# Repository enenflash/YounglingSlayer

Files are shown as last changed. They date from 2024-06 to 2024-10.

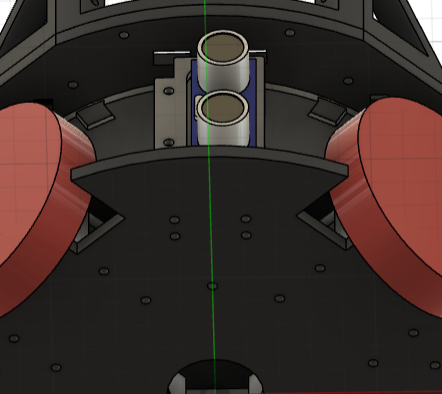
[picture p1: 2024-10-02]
mechanical design/metro/L1.png

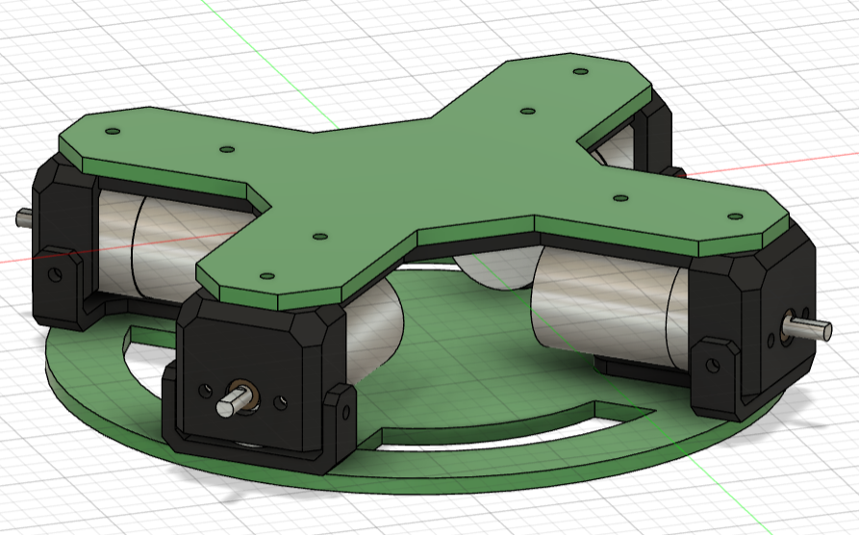
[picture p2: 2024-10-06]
mechanical design/nationals/L2-motors-LS.png

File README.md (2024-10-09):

# YounglingSlayer
Team repository for Robocup Junior Lightweight Australia 2024

## Team Info
- Members: Isabelle Tang (Captain), Ryan Beikrasouli (Programmer), Cruz Barry-Hardy (3D Designer), Albie Gardiner (3D Designer)
- State: Western Australia
- School: Rossmoyne Senior High School

## Programming
We use C++ in [ArduinoIDE](https://www.arduino.cc/en/software/) to program our microcontroller (Teensy 4.1). (See code-explanations)
We also use Raspberry Pi Pico as part of our line sensor.

## 3D Printing
We design our parts in [Fusion360](https://www.autodesk.com/au/products/fusion-360/education). (See mechanical design/)
All parts are printed in PLA.

## PCB Design
We design our PCBs in [KiCAD 7.0](https://www.kicad.org/) and order from [JLCPCB](https://jlcpcb.com/). (See pcbs/).
The schematics are based on circuits we tested using breadboards.

All designs are original other than the [BBR IR Seeker](https://irseeker.buildingblockrobotics.com/)

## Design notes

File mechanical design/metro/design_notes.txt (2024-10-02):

Total weight: 1.372kg

General design notes:
> The motors are not in a perfect 'x' shape but are still at 45 degrees (layout.png).
  - The motors are pushed to the side to give more space for the ball catcher at the front
> We are using breadboards to test out the circuitry and plan to use PCBs later on.
> The wheel size of 7cm was chosen - majority of the design is based on the wheel size (planning.png)
- Last year in standard, our lego wheel size was also ~7cm.

Wheel (wheel/fusion.png):
> The wheel is split into 2 layers of rollers each containing 10 rollers.
> Each roller is wrapped with heatshrink tubing and has a hole for an axle.
(See wheel/assembly.mp4 for assembly)
> A coupling piece is used to attach the wheel to the motor.
- Contains 3mm holes for grub screws to apply pressure on the shaft to prevent the wheel from slipping out.
- The wheel encases the coupling so the layers do not fall off the motor shaft.

Design is split into 3 sections:
> Layer 1 (Bottom layer)
  - holds ultrasonics
  - connects motor mounts from the bottom
> Layer 2 (Middle layer)
  - connects motor mounts from the top
  - goes under IR and has pillars connecting to L3
> Layer 3 (Top layer)
  - goes on top of IR
  - holds components that go on top such as breadboard, battery, switches
  - ball catcher hangs down from L3
  - goal stopper/handle at the back (stops the robot from going into its own goal)

Layer 1 (L1.png):
> Mounts ultrasonics and motor mounts
> Has indents on diagonals for motors

Layer 2 and motor mounts (L2_motor_mounts):
> Motor mounts encase the motor (the motors are attached via 2 screws at the front)
> Pillars on top of L2 go through holes in the IR to connect to L3.

Layer 3 (L3_holes.png):
> Wires (motor wires, ultrasonic wires) come from holes under the breadboard
> Battery is zip-tied using the holes to the left and right of its
> Breadboard is mounted to L3

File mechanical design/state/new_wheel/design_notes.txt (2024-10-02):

> Reduced wheel size from ~7cm to 6.2cm (including rollers)
  - Increase space for ball catcher and ultrasonics
  - Gain more torque from reduced speed
  - Less rollers to deal with when assembling (14 instead of 20 total)
> 2 screw holes and 2 middle plate 'sticks' instead of 4 each
> Coupling is thicker to prevent it from breaking/cracking
> Tighter hole for motor shaft to prevent wobble

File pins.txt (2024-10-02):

// Motor Pins
#define TL_PWM 5
#define TL_DIR 4
#define TR_PWM 6
#define TR_DIR 7
#define BL_PWM 3
#define BL_DIR 2
#define BR_PWM 9
#define BR_DIR 8

// Ultrasonic Pins
#define USR_TRIG 34
#define USR_ECHO 33
#define USL_TRIG 22
#define USL_ECHO 23
#define USB_TRIG 28
#define USB_ECHO 27

// IDLE SWITCH
#define IDLE_PIN 40

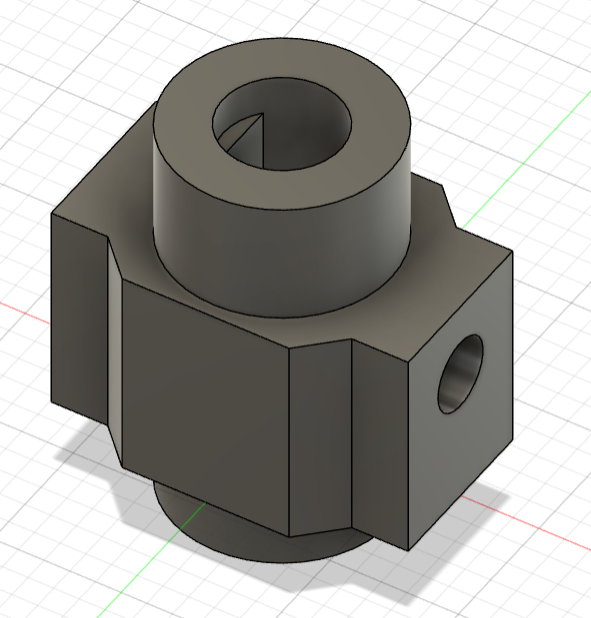
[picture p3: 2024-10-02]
mechanical design/state/new_wheel/coupling.png

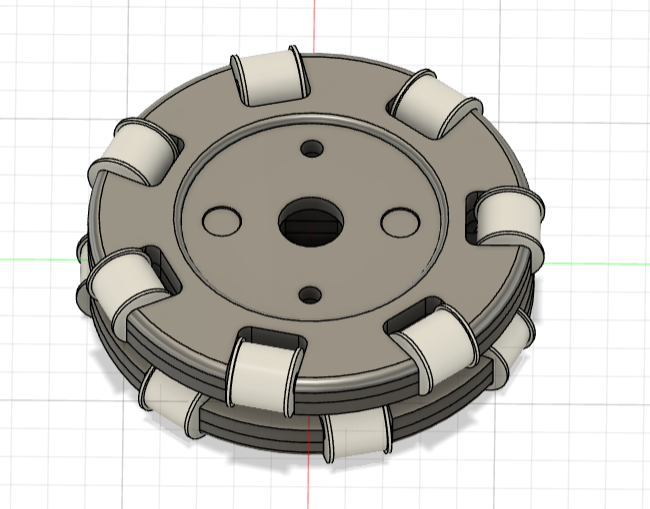
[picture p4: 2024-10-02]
mechanical design/state/new_wheel/6cm_wheel.png

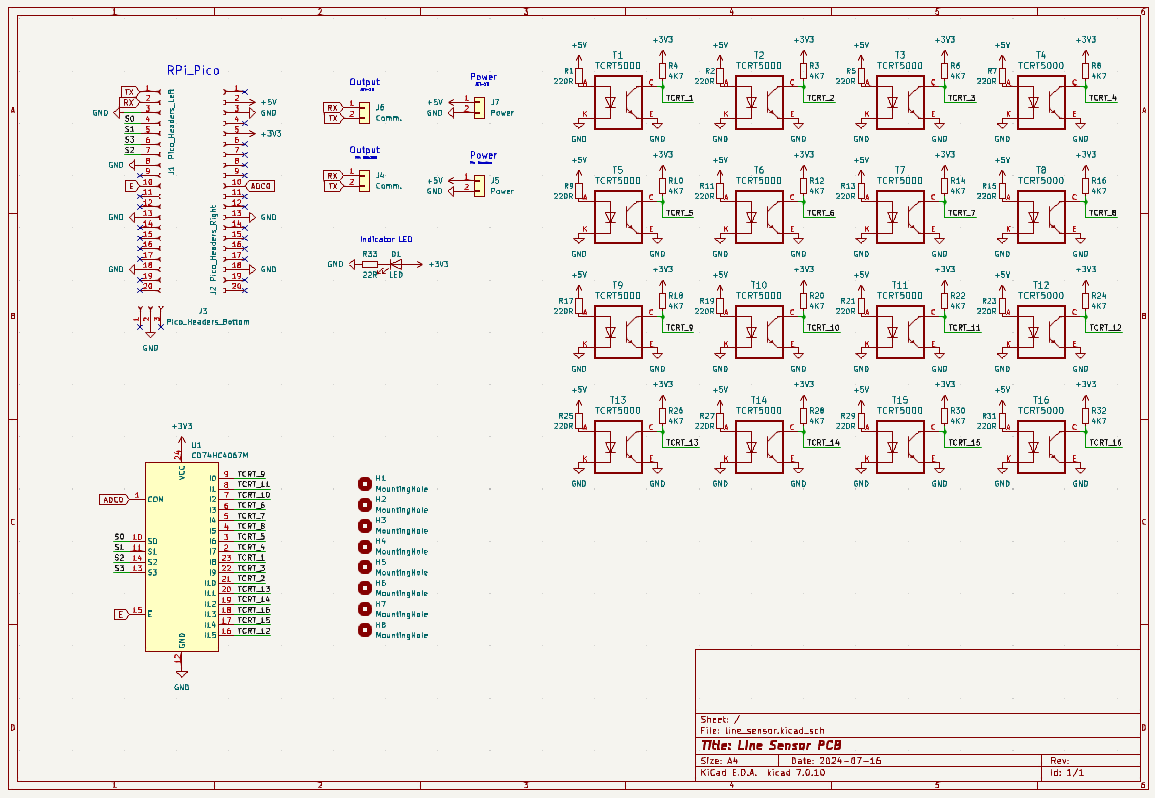
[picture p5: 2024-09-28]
pcbs/line_sensor-26-08/schematic.png

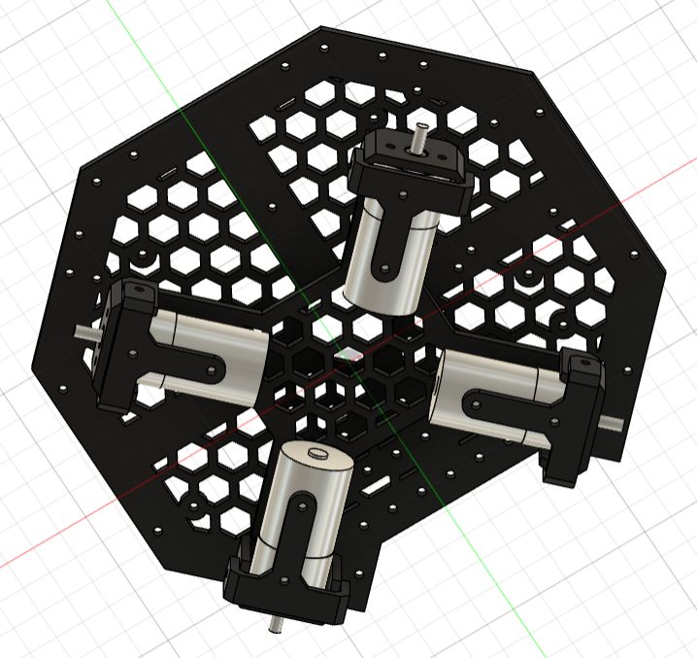
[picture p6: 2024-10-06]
mechanical design/nationals/hexagons.png

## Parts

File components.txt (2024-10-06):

Microcontroller: Teensy 4.1
- Website: https://www.pjrc.com/store/teensy41.html

Battery: 12V Lithium Ion DC
- Website: https://au.lightmalls.com/12v-4000mah-18650-lithium-ion-dc-12-6v-super-rechargeable-battery-pack

IR Sensor: BBR IR Sensor V2 (I2C):
- Website: https://buildingblockrobotics.com/products/ir-seeker (note this is v3)
- Tutorial: https://irseeker.buildingblockrobotics.com/ 

IMU: Adafruit BNO055 9-DOF IMU (I2C)
- Website: https://www.adafruit.com/product/2472
- Tutorial: https://learn.adafruit.com/adafruit-bno055-absolute-orientation-sensor/arduino-code

Adjustable Voltage Step-down: 
- https://www.altronics.com.au/p/z6334-dc-dc-buck-module-3-40v-input/

Ultrasonics: HC-SR04
- https://core-electronics.com.au/hc-sr04-ultrasonic-module-distance-measuring-sensor.html

Bluetooth Module: HC-05
- https://core-electronics.com.au/bluetooth-module-hc-05.html

Line Sensor PCB: Custom made (UART)
- Sub-mcu: Raspberry Pi Pico
- Multiplexer: CD74HC4067M
- Reflective light sensors: TCRT-5000

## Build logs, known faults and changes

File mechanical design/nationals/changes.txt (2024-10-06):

There are 3 new PCBs: (pcbs/)
> Top Board
  - Contains IMU, bluetooth module, switches and battery connector
> Bottom Board
  - Contains Teensy 4.1 and main circuits: motor, ultrasonic and line sensor wires
> Line sensor

Reused parts:
> Ultrasonic mounts and cage pieces
> Goal stopper
> Wheels

L2 and Motors (L2-motors-LS.png)
> The same concept is used where the motors directly attach to L2
> The Line sensor is mounted below the motors and connects to L2

Support pillars
> Metal M3 standoffs are used to connect L2 to the IR mount
  - The metal standoffs are stronger and thinner
  - The bottom board is held between L2 and the metal standoffs
> There are 2 supports above each motor instead of 1

IR mount
> The IR mount is similar to the old one but the ring connecting the dividers is further out

Wheel guards (wheel_guard.png)
> Wheel guards are used to hold the wheels in place
  - Reduces the occurence of wheels falling out
  - Protects wheels from other robots

Wiring (core.png)
> JST-XH headers and housings are used to securely attach component wiring
> Wires are crimped by hand to the exact length needed

Hexagons (hexagons.png)
> Hexagon patterns were added throughout the robot to reduce the weight of printed parts

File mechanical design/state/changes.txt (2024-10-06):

Total Weight: 1.1kg

Structural changes:

> Change in shape
  - Removed the circular shape of the layers to become an octogon
  - Makes positioning of pieces easier

> Removing Layer 1 (bottom_view.png)
  - L1 was removed to lose weight as ultrasonics can be attached from L3

> Combining L2 with motor mounts (L2-motors.png)
  - Motor mounts were removed to lose weight
  - L2 connects to motors directly
  - Support pillars connecting L2 to L3 are printed separately so that a change in height does not requite redesigns of L2

> IR Mount (IR_mount.png, structure.png)
  - L2 connects to the IR mount using support pillars
  - The IR Mount supports the IR from the bottom (not screwed in)
  - It also separates the individual sensors to reduce interference and incorrect readings
  - The IR Mount connects to L3 through the horizontal and vertical square holes

> Goal stopper used as a handle
  - The goal stopper was redesigned to be easily printable and able to be used as a handle

> Double decker breadboard
  - We intended to use PCBs during states but due to delays we had to use breadboards again
  - Half breadboards are stacked over each other to reduce space

> Cage and ultrasonics
  - Instead of mounting ultrasonics from L1 they are mounted directly to the cage
  - The cage hangs from L3 via a single screw
  - Ultrasonics are horizontal to allow them to be lower and make connecting pins easier

> Battery mount
  - Battery is mounted by encasing it instead of zip ties

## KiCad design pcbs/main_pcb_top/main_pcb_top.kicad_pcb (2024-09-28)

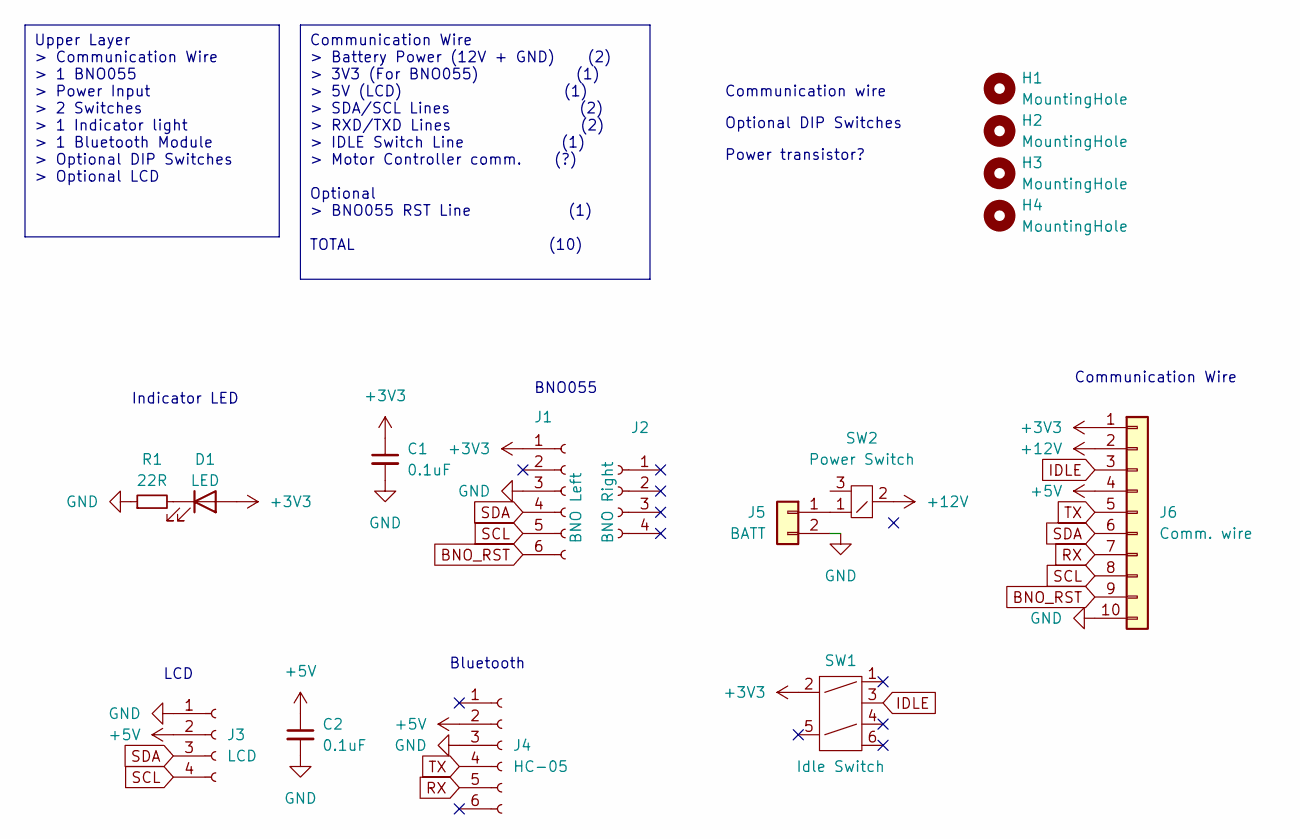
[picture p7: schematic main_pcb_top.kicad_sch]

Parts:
C1, C2: 0.1uF; C_0402_1005Metric
D1: LED; LED_0805_2012Metric
H1, H2, H3, H4: MountingHole; MountingHole_3.2mm_M3_Pad
J1: BNO Left; PinSocket_1x06_P2.54mm_Vertical
J2: BNO Right; PinSocket_1x04_P2.54mm_Vertical
J3: LCD; PinSocket_1x04_P2.54mm_Vertical
J4: HC-05; PinSocket_1x06_P2.54mm_Vertical
J5: BATT; JST_XH_B2B-XH-A_1x02_P2.50mm_Vertical
J6: Comm. wire; IDC-Header_2x05_P2.54mm_Vertical
R1: 22R; R_0805_2012Metric
SW1: Idle Switch; Switch_DPDT_S2060
SW2: Power Switch; Switch_SPDT_S2070

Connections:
+3V3: C1.1, D1.2 (A), J1.1, J6.1, SW1.2
+5V: C2.1, J3.2, J4.2, J6.4
+12V: J6.2, SW2.2
BNO_RST: J1.6, J6.9
GND: C1.2, C2.2, J1.3, J3.1, J4.3, J5.2, J6.10, R1.1
IDLE: J6.3, SW1.3
unnamed: D1.1 (K), R1.2
unnamed: J5.1, SW2.1
RX: J4.5, J6.7
SCL: J1.5, J3.4, J6.8
SDA: J1.4, J3.3, J6.6
TX: J4.4, J6.5

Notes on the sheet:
Upper Layer > Communication Wire > 1 BNO055 > Power Input > 2 Switches > 1 Indicator light > 1 Bluetooth Module > Optional DIP Switches > Optional LCD
Communication Wire > Battery Power (12V + GND) (2) > 3V3 (For BNO055) (1) > 5V (LCD) (1) > SDA/SCL Lines (2) > RXD/TXD Lines (2) > IDLE Switch Line (1) > Motor Controller comm. (?) Optional > BNO055 RST Line (1) TOTAL (10)
Power transistor?
Bluetooth
Communication wire
Optional DIP Switches
BNO055
LCD
Indicator LED
Communication Wire

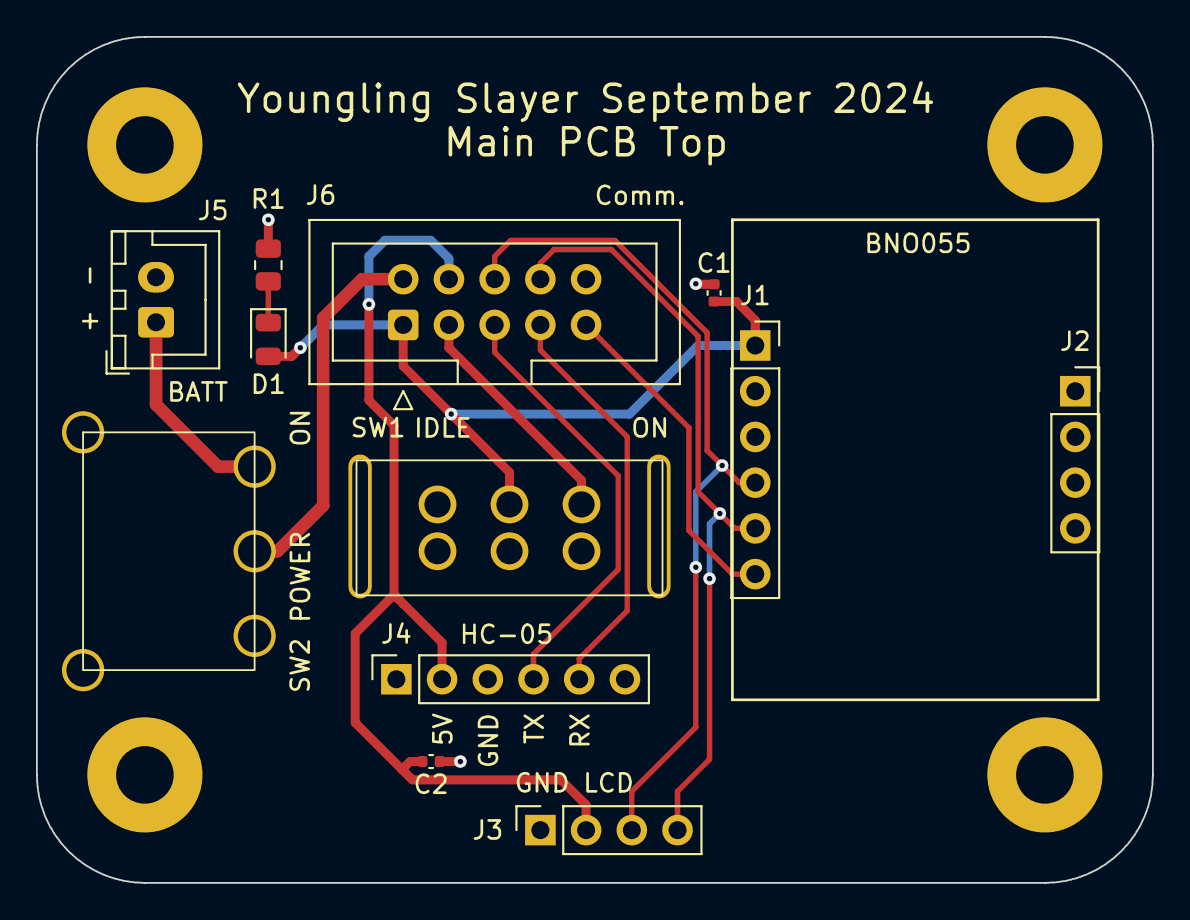
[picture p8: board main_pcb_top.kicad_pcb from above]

Board: 2 copper layers, 62.0 x 47.0 mm, 16 parts (0 on the bottom side), 12 nets.

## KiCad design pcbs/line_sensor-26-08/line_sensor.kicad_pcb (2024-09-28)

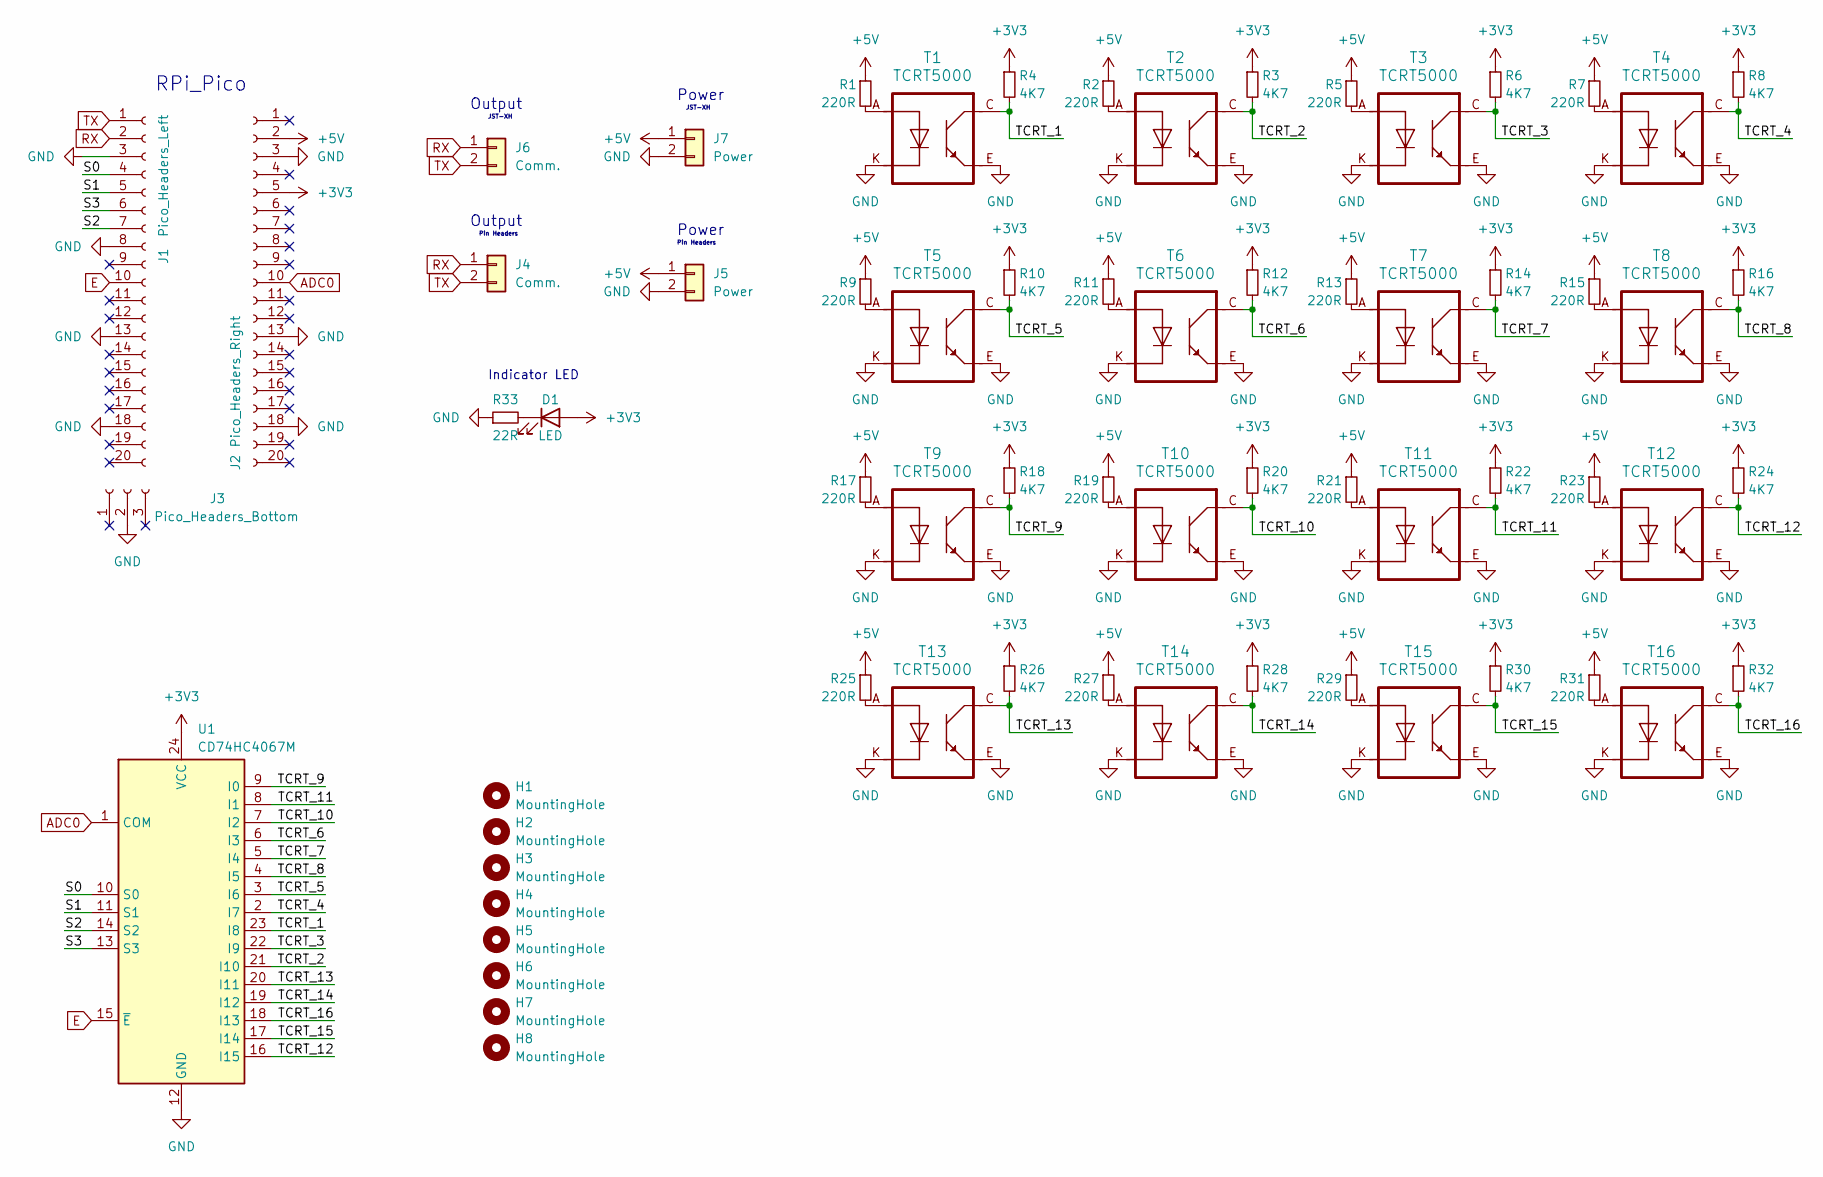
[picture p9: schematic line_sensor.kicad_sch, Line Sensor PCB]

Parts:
D1: LED; LED_0805_2012Metric
H1, H2, H3, H4, H5, H6, H7, H8: MountingHole; MountingHole_3.2mm_M3_Pad
J1: Pico_Headers_Left; PinSocket_1x20_P2.54mm_Vertical
J2: Pico_Headers_Right; PinSocket_1x20_P2.54mm_Vertical
J3: Pico_Headers_Bottom; PinSocket_1x03_P2.54mm_Vertical
J4: Comm.; PinSocket_1x02_P2.54mm_Vertical
J5: Power; PinSocket_1x02_P2.54mm_Vertical
J6: Comm.; JST_XH_B2B-XH-AM_1x02_P2.50mm_Vertical
J7: Power; JST_XH_B2B-XH-AM_1x02_P2.50mm_Vertical
R1, R2, R5, R7, R9, R11, R13, R15, R17, R19, R21, R23, R25, R27, R29, R31: 220R; R_0805_2012Metric
R3, R4, R6, R8, R10, R12, R14, R16, R18, R20, R22, R24, R26, R28, R30, R32: 4K7; R_0805_2012Metric
R33: 22R; R_0805_2012Metric
T1, T2, T3, T4, T5, T6, T7, T8, T9, T10, T11, T12, T13, T14, T15, T16: TCRT5000
U1: CD74HC4067M; SOIC-24W_7.5x15.4mm_P1.27mm

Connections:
+3V3: D1.2 (A), J2.5, R3.1, R4.1, R6.1, R8.1, R10.1, R12.1, R14.1, R16.1, R18.1, R20.1, R22.1, R24.1, R26.1, R28.1, R30.1, R32.1, U1.24 (VCC)
+5V: J2.2, J5.1, J7.1, R1.1, R2.1, R5.1, R7.1, R9.1, R11.1, R13.1, R15.1, R17.1, R19.1, R21.1, R23.1, R25.1, R27.1, R29.1, R31.1
/S0: J1.4, U1.10 (S0)
/S1: J1.5, U1.11 (S1)
/S2: J1.7, U1.14 (S2)
/S3: J1.6, U1.13 (S3)
/TCRT_1: R4.2, T1.C (Collector), U1.23 (I8)
/TCRT_2: R3.2, T2.C (Collector), U1.21 (I10)
/TCRT_3: R6.2, T3.C (Collector), U1.22 (I9)
/TCRT_4: R8.2, T4.C (Collector), U1.2 (I7)
/TCRT_5: R10.2, T5.C (Collector), U1.3 (I6)
/TCRT_6: R12.2, T6.C (Collector), U1.6 (I3)
/TCRT_7: R14.2, T7.C (Collector), U1.5 (I4)
/TCRT_8: R16.2, T8.C (Collector), U1.4 (I5)
/TCRT_9: R18.2, T9.C (Collector), U1.9 (I0)
/TCRT_10: R20.2, T10.C (Collector), U1.7 (I2)
/TCRT_11: R22.2, T11.C (Collector), U1.8 (I1)
/TCRT_12: R24.2, T12.C (Collector), U1.16 (I15)
/TCRT_13: R26.2, T13.C (Collector), U1.20 (I11)
/TCRT_14: R28.2, T14.C (Collector), U1.19 (I12)
/TCRT_15: R30.2, T15.C (Collector), U1.17 (I14)
/TCRT_16: R32.2, T16.C (Collector), U1.18 (I13)
ADC0: J2.10, U1.1 (COM)
E: J1.10, U1.15 (~E)
GND: J1.3, J1.8, J1.13, J1.18, J2.3, J2.13, J2.18, J3.2, J5.2, J7.2, R33.1, T1.E (Emitter), T1.K (Cathode), T2.E (Emitter), T2.K (Cathode), T3.E (Emitter), T3.K (Cathode), T4.E (Emitter), T4.K (Cathode), T5.E (Emitter), T5.K (Cathode), T6.E (Emitter), T6.K (Cathode), T7.E (Emitter), T7.K (Cathode), T8.E (Emitter), T8.K (Cathode), T9.E (Emitter), T9.K (Cathode), T10.E (Emitter), T10.K (Cathode), T11.E (Emitter), T11.K (Cathode), T12.E (Emitter), T12.K (Cathode), T13.E (Emitter), T13.K (Cathode), T14.E (Emitter), T14.K (Cathode), T15.E (Emitter), T15.K (Cathode), T16.E (Emitter), T16.K (Cathode), U1.12 (GND)
unnamed: D1.1 (K), R33.2
unnamed: R1.2, T1.A (Anode)
unnamed: R2.2, T2.A (Anode)
unnamed: R5.2, T3.A (Anode)
unnamed: R7.2, T4.A (Anode)
unnamed: R9.2, T5.A (Anode)
unnamed: R11.2, T6.A (Anode)
unnamed: R13.2, T7.A (Anode)
unnamed: R15.2, T8.A (Anode)
unnamed: R17.2, T9.A (Anode)
unnamed: R19.2, T10.A (Anode)
unnamed: R21.2, T11.A (Anode)
unnamed: R23.2, T12.A (Anode)
unnamed: R25.2, T13.A (Anode)
unnamed: R27.2, T14.A (Anode)
unnamed: R29.2, T15.A (Anode)
unnamed: R31.2, T16.A (Anode)
RX: J1.2, J4.1, J6.1
TX: J1.1, J4.2, J6.2

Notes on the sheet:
Output
Power
RPi_Pico
JST-XH
Pin Headers
Indicator LED

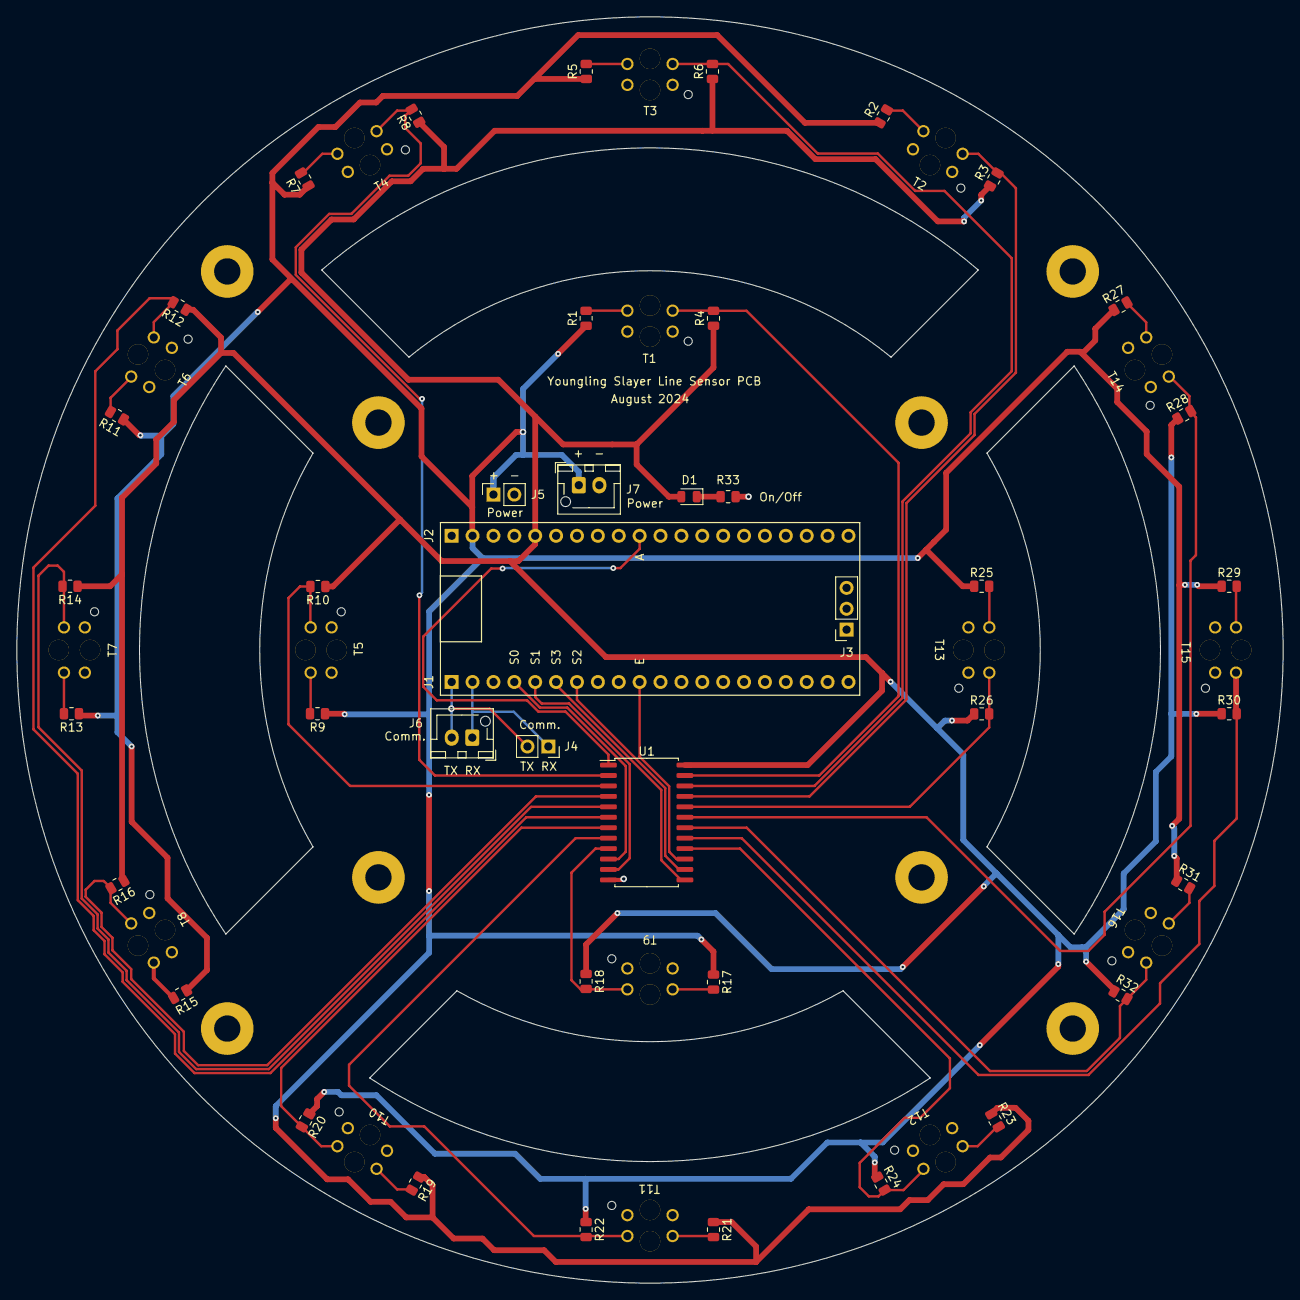
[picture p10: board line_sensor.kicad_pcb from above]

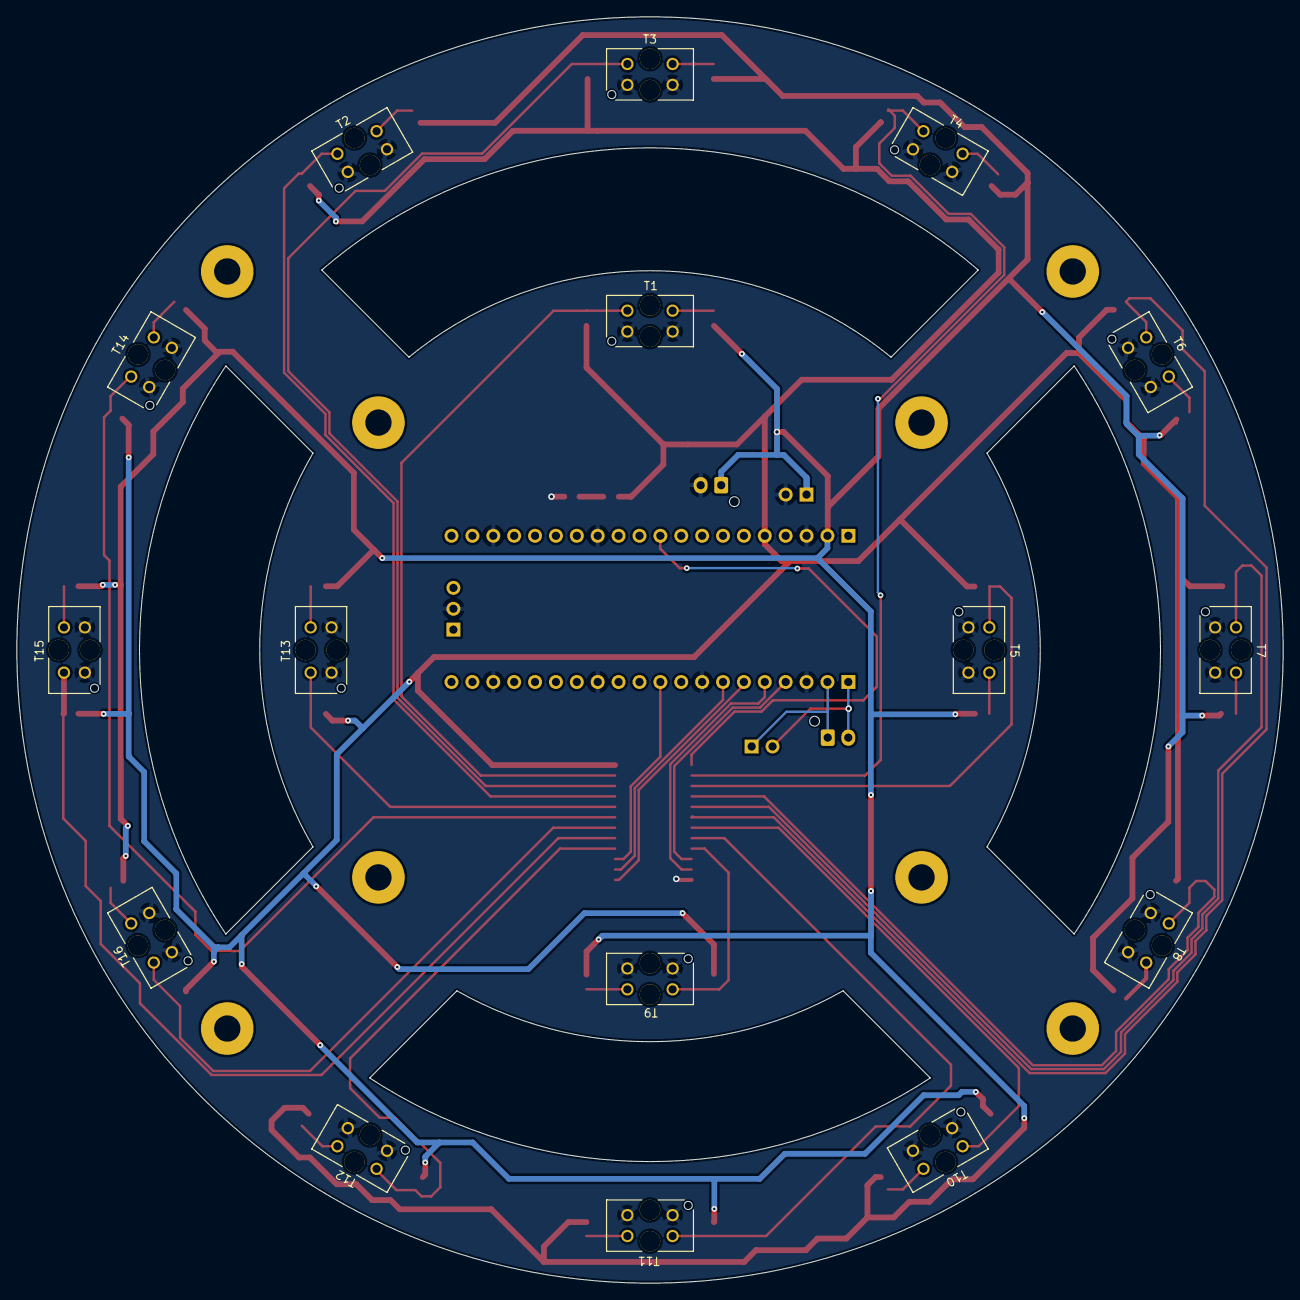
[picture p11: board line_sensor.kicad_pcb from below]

Board: 2 copper layers, 154.0 x 154.0 mm, 66 parts (16 on the bottom side), 44 nets.

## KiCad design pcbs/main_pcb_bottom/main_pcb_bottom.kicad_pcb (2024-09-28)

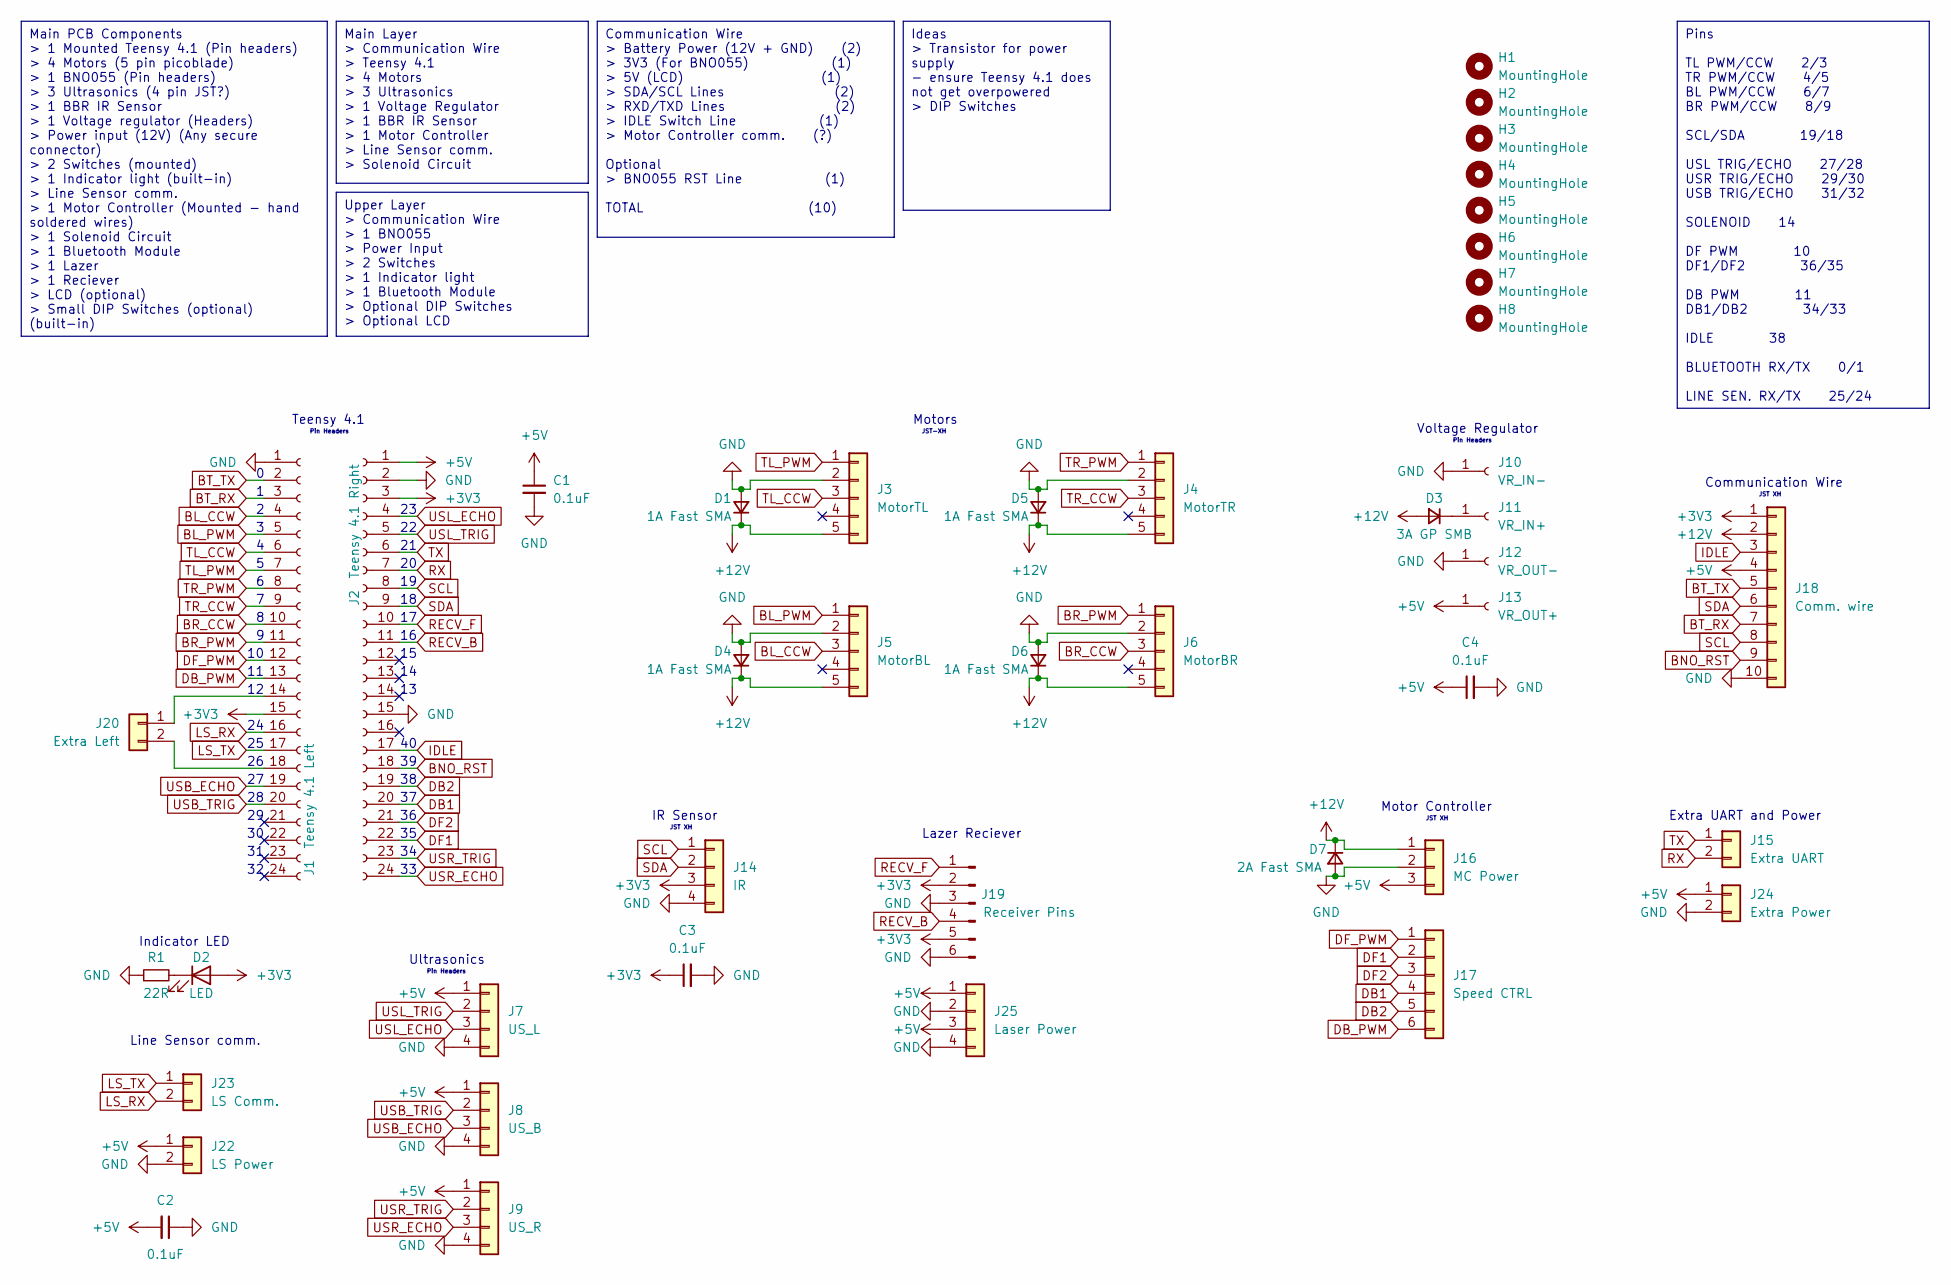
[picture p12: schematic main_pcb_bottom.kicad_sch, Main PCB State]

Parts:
C1, C2, C3, C4: 0.1uF; C_0402_1005Metric
D1, D4, D5, D6: 1A Fast SMA; D_SMA
D2: LED; LED_0805_2012Metric_Pad1.15x1.40mm_HandSolder
D3: 3A GP SMB; D_SMB
D7: 2A Fast SMA; D_SMA
H1, H2, H3, H4, H5, H6, H7, H8: MountingHole; MountingHole_3.2mm_M3_Pad
J1: Teensy 4.1 Left; PinSocket_1x24_P2.54mm_Vertical
J2: Teensy 4.1 Right; PinSocket_1x24_P2.54mm_Vertical
J3: MotorTL; JST_XH_B5B-XH-AM_1x05_P2.50mm_Vertical
J4: MotorTR; JST_XH_B5B-XH-AM_1x05_P2.50mm_Vertical
J5: MotorBL; JST_XH_B5B-XH-AM_1x05_P2.50mm_Vertical
J6: MotorBR; JST_XH_B5B-XH-AM_1x05_P2.50mm_Vertical
J7: US_L; JST_XH_B4B-XH-AM_1x04_P2.50mm_Vertical
J8: US_B; JST_XH_B4B-XH-AM_1x04_P2.50mm_Vertical
J9: US_R; JST_XH_B4B-XH-AM_1x04_P2.50mm_Vertical
J10: VR_IN-; PinSocket_1x01_P2.54mm_Vertical
J11: VR_IN+; PinSocket_1x01_P2.54mm_Vertical
J12: VR_OUT-; PinSocket_1x01_P2.54mm_Vertical
J13: VR_OUT+; PinSocket_1x01_P2.54mm_Vertical
J14: IR; JST_XH_B4B-XH-AM_1x04_P2.50mm_Vertical
J15: Extra UART; JST_XH_B2B-XH-AM_1x02_P2.50mm_Vertical
J16: MC Power; JST_XH_B3B-XH-AM_1x03_P2.50mm_Vertical
J17: Speed CTRL; JST_XH_B6B-XH-AM_1x06_P2.50mm_Vertical
J18: Comm. wire; IDC-Header_2x05_P2.54mm_Vertical
J19: Receiver Pins; PinHeader_1x06_P2.54mm_Vertical
J20: Extra Left; PinSocket_1x02_P2.54mm_Vertical
J22: LS Power; JST_XH_B2B-XH-AM_1x02_P2.50mm_Vertical
J23: LS Comm.; JST_XH_B2B-XH-AM_1x02_P2.50mm_Vertical
J24: Extra Power; JST_XH_B2B-XH-AM_1x02_P2.50mm_Vertical
J25: Laser Power; PinHeader_1x04_P2.54mm_Vertical
R1: 22R; R_0805_2012Metric_Pad1.20x1.40mm_HandSolder

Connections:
+3V3: C3.1, D2.2 (A), J1.15, J2.3, J14.3, J18.1, J19.2, J19.5
+5V: C1.1, C2.2, C4.1, J2.1, J7.1, J8.1, J9.1, J13.1, J16.3, J18.4, J22.1, J24.1, J25.1, J25.3
+12V: D1.1 (K), D3.2 (A), D4.1 (K), D5.1 (K), D6.1 (K), D7.1 (K), J3.5, J4.5, J5.5, J6.5, J16.1, J18.2
BL_CCW: J1.4, J5.3
BL_PWM: J1.5, J5.1
BNO_RST: J2.18, J18.9
BR_CCW: J1.10, J6.3
BR_PWM: J1.11, J6.1
BT_RX: J1.3, J18.7
BT_TX: J1.2, J18.5
DB1: J2.20, J17.4
DB2: J2.19, J17.5
DB_PWM: J1.13, J17.6
DF1: J2.22, J17.2
DF2: J2.21, J17.3
DF_PWM: J1.12, J17.1
GND: C1.2, C2.1, C3.2, C4.2, D1.2 (A), D4.2 (A), D5.2 (A), D6.2 (A), D7.2 (A), J1.1, J2.2, J2.15, J3.2, J4.2, J5.2, J6.2, J7.4, J8.4, J9.4, J10.1, J12.1, J14.4, J16.2, J18.10, J19.3, J19.6, J22.2, J24.2, J25.2, J25.4, R1.1
IDLE: J2.17, J18.3
LS_RX: J1.16, J23.2
LS_TX: J1.17, J23.1
unnamed: D2.1 (K), R1.2
unnamed: D3.1 (K), J11.1
unnamed: J1.14, J20.1
unnamed: J1.18, J20.2
RECV_B: J2.11, J19.4
RECV_F: J2.10, J19.1
RX: J2.7, J15.2
SCL: J2.8, J14.1, J18.8
SDA: J2.9, J14.2, J18.6
TL_CCW: J1.6, J3.3
TL_PWM: J1.7, J3.1
TR_CCW: J1.9, J4.3
TR_PWM: J1.8, J4.1
TX: J2.6, J15.1
USB_ECHO: J1.19, J8.3
USB_TRIG: J1.20, J8.2
USL_ECHO: J2.4, J7.3
USL_TRIG: J2.5, J7.2
USR_ECHO: J2.24, J9.3
USR_TRIG: J2.23, J9.2

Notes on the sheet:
Upper Layer > Communication Wire > 1 BNO055 > Power Input > 2 Switches > 1 Indicator light > 1 Bluetooth Module > Optional DIP Switches > Optional LCD
Main Layer > Communication Wire > Teensy 4.1 > 4 Motors > 3 Ultrasonics > 1 Voltage Regulator > 1 BBR IR Sensor > 1 Motor Controller > Line Sensor comm. > Solenoid Circuit
Main PCB Components > 1 Mounted Teensy 4.1 (Pin headers) > 4 Motors (5 pin picoblade) > 1 BNO055 (Pin headers) > 3 Ultrasonics (4 pin JST?) > 1 BBR IR Sensor > 1 Voltage regulator (Headers) > Power input (12V) (Any secure connector) > 2 Switches (mounted) > 1 Indicator light (built-in) > Line Senso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
Pins TL PWM/CCW 2/3 TR PWM/CCW 4/5 BL PWM/CCW 6/7 BR PWM/CCW 8/9 SCL/SDA 19/18 USL TRIG/ECHO 27/28 USR TRIG/ECHO 29/30 USB TRIG/ECHO 31/32 SOLENOID 14 DF PWM 10 DF1/DF2 36/35 DB PWM 11 DB1/DB2 34/33 IDLE 38 BLUETOOTH RX/TX 0/1 LINE SEN. RX/TX 25/24
Ideas > Transistor for power supply - ensure Teensy 4.1 does not get overpowered > DIP Switches
Communication Wire > Battery Power (12V + GND) (2) > 3V3 (For BNO055) (1) > 5V (LCD) (1) > SDA/SCL Lines (2) > RXD/TXD Lines (2) > IDLE Switch Line (1) > Motor Controller comm. (?) Optional > BNO055 RST Line (1) TOTAL (10)
Motors
JST-XH
Teensy 4.1
Communication Wire
Lazer Reciever
JST XH
Pin Headers
Line Sensor comm.
Voltage Regulator
Indicator LED
IR Sensor
Motor Controller
Extra UART and Power
Ultrasonics

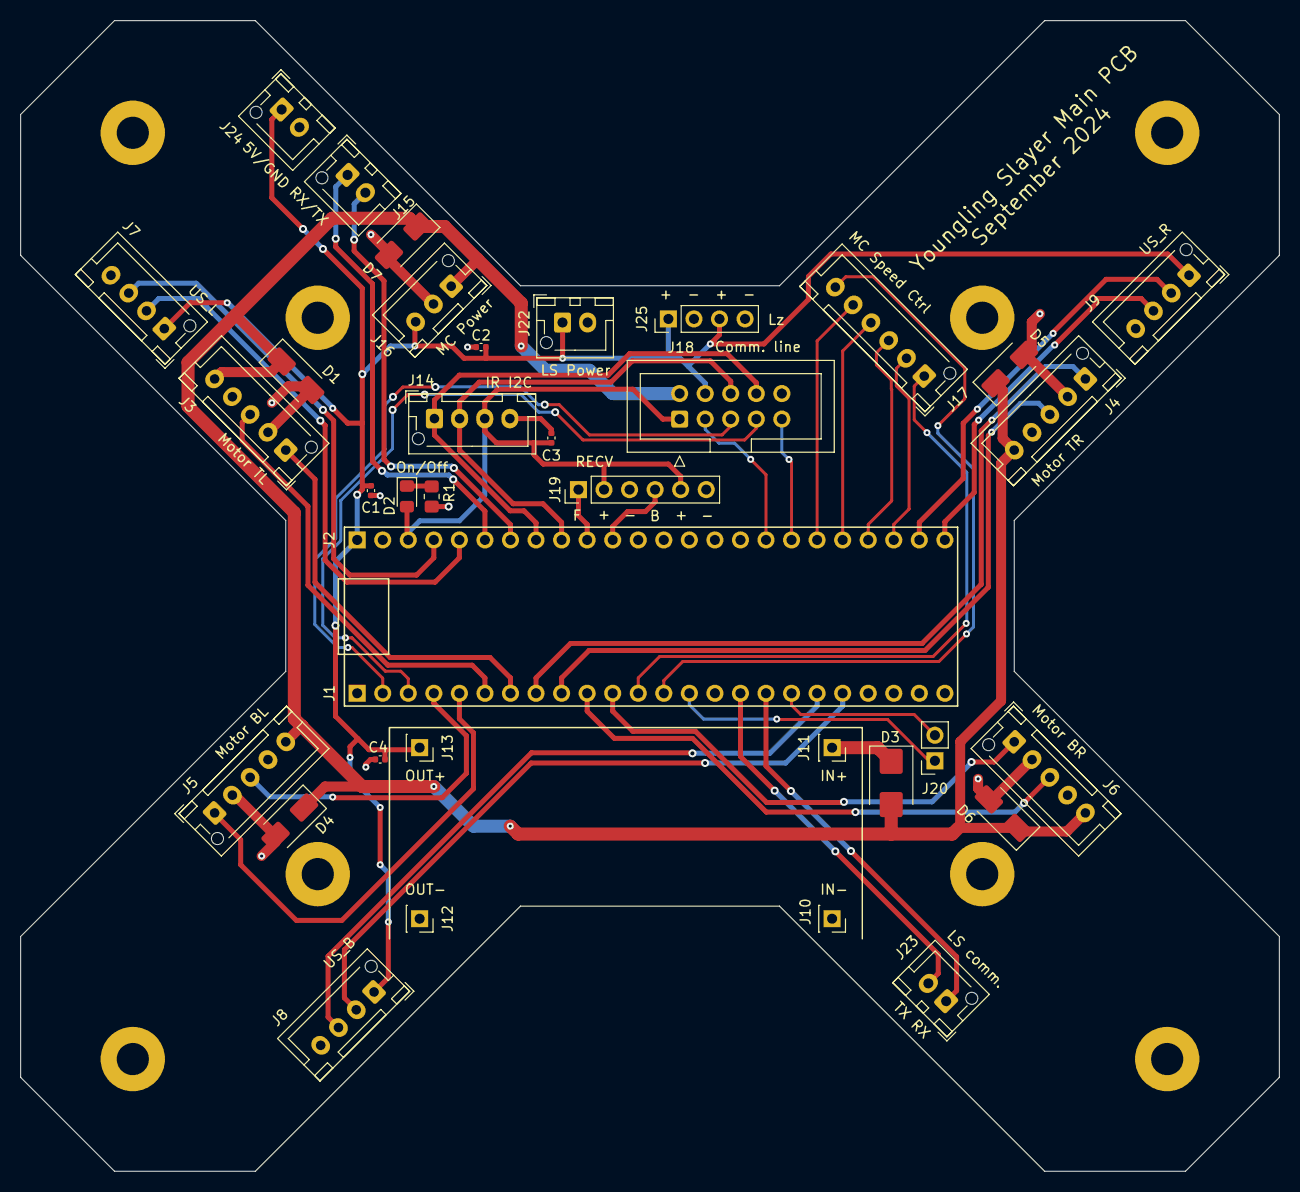
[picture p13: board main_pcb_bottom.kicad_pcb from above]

Board: 2 copper layers, 125.1 x 114.4 mm, 44 parts (0 on the bottom side), 40 nets.

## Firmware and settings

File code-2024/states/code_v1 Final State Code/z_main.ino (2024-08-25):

//IMU gyro;
Adafruit_BNO055 bno = Adafruit_BNO055(55);

//IR
IRSensor ir;
int direction, strength, raw_direction, raw_strength;

MotorController mc = MotorController(false);
Ultrasonic left_ultrasonic = Ultrasonic(LU_TRIG, LU_ECHO);
Ultrasonic right_ultrasonic = Ultrasonic(RU_TRIG, RU_ECHO);
Ultrasonic back_ultrasonic = Ultrasonic(BU_TRIG, BU_ECHO);

float tilt, triangle_tilt, goal_tilt;
int ult_distance, left_distance, right_distance,back_distance;
int true_left_distance, true_right_distance, true_back_distance;
String ultrasonic_side, position;


vector<int> direction_history = {};
vector<int> strength_history = {};
vector<int> left_distance_history;
vector<int> right_distance_history;
vector<int> back_distance_history;

// Setup
void setup() {
  Serial.begin(9600);
  Serial.println("\nRobot Initialized");
  /* :::::::: MOTOR PINS :::::::: */

  pinMode(TL_PWM, OUTPUT);
  pinMode(TR_PWM, OUTPUT);
  pinMode(BL_PWM, OUTPUT);
  pinMode(BR_PWM, OUTPUT);

  analogWriteFrequency(TL_PWM, 20000);
  analogWriteFrequency(TR_PWM, 20000);
  analogWriteFrequency(BL_PWM, 20000);
  analogWriteFrequency(BR_PWM, 20000);

  pinMode(TL_DIR, OUTPUT);
  pinMode(TR_DIR, OUTPUT);
  pinMode(BL_DIR, OUTPUT);
  pinMode(BR_DIR, OUTPUT);

  pinMode(BU_TRIG, OUTPUT);
  pinMode(LU_TRIG, OUTPUT);
  pinMode(RU_TRIG, OUTPUT);
  pinMode(BU_ECHO, INPUT);
  pinMode(LU_ECHO, INPUT);
  pinMode(RU_ECHO, INPUT);

  pinMode(SWITCH_PIN, INPUT_PULLDOWN);

  mc.stopMotors();
  
  //imu
  if (!bno.begin()) { Serial.print("\nNo BNO055 detected"); }
  else { Serial.print("\nBNO055 Initialized"); }
  bno.setExtCrystalUse(true);

  //ir
  Wire.begin();
}

float x,y;
bool run_forward = false;
void loop() {
  // imu
  sensors_event_t event;
  bno.getEvent(&event);
  tilt = event.orientation.x;

  tilt = 360 - tilt;

  //ir
  ir.readData();
  raw_direction = ir.getDirection(); 
  direction_history.insert(direction_history.end(), raw_direction);
  if (direction_history.size() > 5) direction_history.erase(direction_history.begin());
  direction = Most_Common(direction_history);
  
  raw_strength = ir.getStrength();
  if (raw_strength != 0) {strength_history.insert(strength_history.end(), raw_strength);}
  
  if (strength_history.size() > 3) strength_history.erase(strength_history.begin());
  strength = Average(strength_history);

  int ball_distance = 100-strength;


  // Ultrasonic
  // get raw distances
    left_distance = left_ultrasonic.get_distance();
    right_distance = right_ultrasonic.get_distance();
    back_distance = back_ultrasonic.get_distance();

    // get true distances (accounting for tilt of robot)
    true_left_distance = Get_True_Distance(left_distance, triangle_tilt) + ULTRASONIC_TO_ROBOT;
    true_right_distance = Get_True_Distance(right_distance, triangle_tilt) + ULTRASONIC_TO_ROBOT;
    true_back_distance = Get_True_Distance(back_distance, triangle_tilt) + ULTRASONIC_TO_ROBOT;
    back_distance_history.insert(back_distance_history.end(), true_back_distance);

    // shorten histories
    if (left_distance_history.size() > 5) { left_distance_history.erase(left_distance_history.begin()); }
    if (right_distance_history.size() > 5) { right_distance_history.erase(right_distance_history.begin()); }
    if (back_distance_history.size() > 5) { back_distance_history.erase(back_distance_history.begin()); }

    true_back_distance = Average(back_distance_history);

    // ultrasonic side
    ultrasonic_side = ultrasonic_side_chooser(true_left_distance, true_right_distance, left_distance_history, right_distance_history, FIELD_WIDTH, ULTRASONIC_TO_ROBOT);

    if (ultrasonic_side == "LEFT") {
      left_distance_history.insert(left_distance_history.end(), true_left_distance);
      ult_distance = Average(left_distance_history);
      true_left_distance = ult_distance; 
    }

    // turn the right ult_distance into the left ult_distance
    else if (ultrasonic_side == "RIGHT") {
      right_distance_history.insert(right_distance_history.end(), true_right_distance);
      true_right_distance = Average(right_distance_history);
      ult_distance  = FIELD_WIDTH - true_right_distance;
    }

    // ult_distance set to 808 to indicate that neither ultrasonic should be used
    else {
      left_distance_history.insert(left_distance_history.end(), true_left_distance);
      ult_distance = Average(left_distance_history);
      true_left_distance = ult_distance;
    }

    //if (true_left_distance != 0){
    //  left_distance_history.insert(left_distance_history.end(), true_left_distance);
    //}
    
    //ult_distance = Average(left_distance_history);


    position = Find_Position(ult_distance, FIELD_WIDTH, ULTRASONIC_TO_ROBOT);
    
  if (true) {
    if (!run_forward) {
      unsigned long startTime = millis();  // Get the start time
      while (millis() - startTime < 800) {
        mc.runMotors(0, 1, tilt);
      }
      run_forward = true;
    }

    if (in({8,7,6,5,4},direction)) {mc.setSpeed(50);}
    else {mc.setSpeed(70);}
    x = get_xy(direction, ball_distance, ROBOT_TO_BALL, ROBOT_TO_BALL_MULTIPLY, ir_angles)[0];
    y = get_xy(direction, ball_distance, ROBOT_TO_BALL, ROBOT_TO_BALL_MULTIPLY, ir_angles)[1];
    //goal_tilt = Get_Goal_Tilt(true_back_distance, ult_distance, position, FIELD_HEIGHT, ULTRASONIC_TO_ROBOT, FIELD_WIDTH, direction, strength);
    //x = Line_Check_X(ult_distance, x, direction);
    //y = Line_Check_Y(true_back_distance, y);

    if (direction == 12 and ball_distance < MIN_BALL_DISTANCE) {
      goal_tilt = Hard_Goal_Tilt(position);
    }
    else {
      goal_tilt = 0;
    }

    mc.runMotors(x, y, tilt - (goal_tilt/2));
  }
  
  else {
    mc.stopMotors();
  }
  digitalWrite(13, HIGH);
  delay(100);
}

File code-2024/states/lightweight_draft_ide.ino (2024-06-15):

// Authors: Ryan Beikrasouli and Isabelle Tang (Youngling Slayer)
// logic based off of our (Rossmoyne Cosine) standard competition logic (2023)
// note all mesurements are in cm as the ultrasonics mesure in cm
// NOTE run forward at start, lcd and laser codes have been commented out
#include <iostream>
#include <vector>   // add vectors (equvilent of python lists)
#include <map>      // add std::maps (equivilent of python dictionaries)
#include <iomanip>  // set persision for decimal points
#include <math.h>   // math library
#include <cmath>    // math library for trig
#include <any>      // dynamic variable type
#include <Wire.h>   // used for I2C communicaiton with BBR sensor
#include <Adafruit_Sensor.h>  // gyro sensor 
#include <Adafruit_BNO055.h>  // gyro sensor 
#include <utility/imumaths.h> // gyro sensor
#include <LiquidCrystal_I2C.h> // used for LCD

// Ignoring unimportant warnings
//#pragma GCC diagnostic ignored "-Wmaybe-uninitialized"
#pragma GCC diagnostic ignored "-Wrange-loop-construct"
#pragma GCC diagnostic ignored "-Wunused-but-set-variable"

using namespace std;

// Initialising gyro
Adafruit_BNO055 bno = Adafruit_BNO055(55);

// PINS
const int FRONT_LDR_PIN = A0; // (pin 14)
const int SWITCH_PIN = 30;
LiquidCrystal_I2C lcd(0x3F, 16, 2); // LCD

// ############################### FUNCTIONS ###############################

  // find max value in vector
  int16_t find_max(vector<int16_t> vec) {
    int16_t max = vec[0];

    for (unsigned i = 0; i < vec.size(); i++) {
      if (vec[i] > max) {
        max = vec[i];
      }
    }

    return max;
  }

  // find min value in vector
  int16_t find_min(vector<int16_t> vec) {
    int16_t min = vec[0];

    for (unsigned i = 0; i<vec.size(); i++) {
      if (vec[i] < min) {
        min = vec[i];
      }
    }

    return min;
  }

  // find most common value in vector
  int16_t Most_Common(vector<int16_t> vec){
    int16_t Count = 0;
    int16_t item = 0;

    for (unsigned i = 0; i<vec.size(); i++) {
        if (count(vec.begin(), vec.end(), vec[i]) > Count) {
          item = vec[i];
          Count = count(vec.begin(), vec.end(), vec[i]);
        }
    }
    return item;
    
  }

  long Most_Common(vector<long> vec) {
    int16_t Count = 0;
    long item = 0;

    for (unsigned i = 0; i<vec.size(); i++) {
        if (count(vec.begin(), vec.end(), vec[i]) > Count) {
          item = vec[i];
          Count = count(vec.begin(), vec.end(), vec[i]);
        }
    }
    return item;
    
  }

  // check if element is in vector
  bool in(vector<int16_t> var, int16_t element) {
    vector<int16_t>::iterator it = find(var.begin(), var.end(), element);

    if (it != var.end()) {
      return true;
    }

    else {
      return false;
    }
  }

  // convert degree to radians
  double deg_to_rad(double deg) {
    return deg * M_1_PI / 180;
  }

  // convert ratio of speed of different motors to percentage
  vector<int16_t> raw_to_run(vector<int16_t> raw, int16_t speed) {
    int16_t max_raw = find_max(raw);
    int16_t min_raw = find_min(raw);
    int16_t highest;

    // finding the highest percentage
    if (max_raw > min_raw * -1) {
      highest = max_raw;
    }

    else {
      highest = min_raw * -1;
    }

    // setting highest percentage as 100% of speed and scalling everything reletive to it
    if (highest != 0) {
      vector<int16_t> run = {};
      for (unsigned i = 0; i<raw.size(); i++) {
        run.insert(run.end(), round(raw[i] / highest * speed));
      }
      return run;
    }

    else {
      return { 0, 0, 0, 0 };
    }
  }

  // determines position of robot and returns string of position
  string find_position(int16_t true_distance, string ultrasonic_side) {
    const int16_t HALF_WIDTH = 91;
    
    // right ultrasonic
    if (ultrasonic_side == "RIGHT"){
      if (HALF_WIDTH - 20 <= true_distance and true_distance <= HALF_WIDTH + 20) {
        return "CENTER";
      }

      else if (true_distance < HALF_WIDTH) {
        return "RIGHT";
      }

      else {
        return "LEFT";
      }
    }

    // left ultrasonic
    else if (ultrasonic_side == "LEFT"){
      if (HALF_WIDTH - 20 <= true_distance and true_distance <= HALF_WIDTH + 20) {
        return "CENTER";
      }

      else if (true_distance < HALF_WIDTH) {
        return "LEFT";
      }

      else {
        return "RIGHT";
      }
    }

    else {
      return "CENTER";
    }
  }

  // determine the x y coordinants required to travel to
  vector<double> get_xy(int16_t direction, int16_t ball_distance, int16_t ROBOT_TO_BALL, int16_t ROBOT_TO_BALL_MULTIPLY, std::map<int16_t, double_t> sine, std::map<int16_t, double_t> cosine) {
    double x = 0;
    double y = 0;

    // if ball behind robot move to side instead
    if (in({ 2, 10, 11, 1, 3, 9 }, direction)) {
      if (ball_distance < 23 or in({ 3, 9 }, direction)) {
        y = sine[direction] * ball_distance - ROBOT_TO_BALL;
      }

      else {
        y = sine[direction] * ball_distance - (ROBOT_TO_BALL / 1.5);
      }
    }

    else {
      y = sine[direction] * ball_distance;
    }

    if (in({ 4, 5, 6 }, direction)) {
      x = cosine[direction] * ball_distance + (ROBOT_TO_BALL * ROBOT_TO_BALL_MULTIPLY);
    }

    else if (in({ 7, 8 }, direction)) {
      x = cosine[direction] * ball_distance - (ROBOT_TO_BALL * ROBOT_TO_BALL_MULTIPLY);
    }

    else if (in({ 3, 9, 10, 2, 1, 11 }, direction)) {
      x = cosine[direction] * ball_distance;
    }

    else if (direction == 0) {
      x = 0;
      y = 0;
    }

    else if (direction == 12) {
      x = 0;
    }

    return { x, y };
  }

  // determine tilt based on ball direction and position
  int goal_tilt(int16_t direction, int16_t ball_distance, string pos){//, bool got_ball) {
    if (pos == "CENTER") {
      return 0;
    }

    if (pos == "LEFT") {// and got_ball) {
      return  25;
    }

    if (pos == "RIGHT") {// and got_ball) {
      return  -25;
    }

    return 0;
  }

  // determine which ultrasonic (left/right) to use
  string ultrasonic_side_chooser(int16_t left_distance, int16_t right_distance, vector<int16_t> left_distance_history, vector<int16_t> right_distance_history ) {
    const int16_t FIELD_WIDTH = 182;
    const int16_t ULRASONIC_TO_ROBOT = 9;
    bool sensor_blocked;
    
    // determine if one of the sensors is being blocked by an obstical
    if ((left_distance + right_distance + 2 * ULRASONIC_TO_ROBOT) < FIELD_WIDTH - 20) {
      sensor_blocked = true;
    }

    else {
      sensor_blocked = false;
    }

    if (sensor_blocked) {
      
      // most common left and right distances

      int16_t common_left_distance = Most_Common(left_distance_history);
      int16_t common_right_distance = Most_Common(right_distance_history);

      // determine which (if any) sensor to believe

      // right sensor blocked
      if (right_distance > common_right_distance + 10 and not (left_distance > common_left_distance + 10)) {
        return "LEFT";
      }
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

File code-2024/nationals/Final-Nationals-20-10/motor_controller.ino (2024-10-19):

//Motor controls individual motors on a hardware level
class Motor {
public:
	int PWM_PIN;
	int DIR_PIN;
	Motor(int pwm_pin, int dir_pin) {
		PWM_PIN = pwm_pin;
		DIR_PIN = dir_pin;
	};
  // run the motor
	void run(float speedPercent) {
    int pwmSpeed = (100 - abs(speedPercent)) / 100 * 255;
    //pwm speed and clockwise derived
    if (speedPercent > 0) {
      digitalWrite(DIR_PIN, LOW);
    }
    else {
      digitalWrite(DIR_PIN, HIGH);
    }

    analogWrite(PWM_PIN, pwmSpeed);
	};
  // stop the motor
	void stop() {
    analogWrite(PWM_PIN, 255);
	};
};

//Motor controller interacts with 4 Motors
//MotorController(bool headlessMode)
class MotorController {
private:
  // variable initilisation
  bool headless;
  float speed = 100.0;
  array<float, 4> motorSpeeds;

  // motor objects
  Motor TL = Motor(TL_PWM, TL_DIR);
  Motor TR = Motor(TR_PWM, TR_DIR);
  Motor BL = Motor(BL_PWM, BL_DIR);
  Motor BR = Motor(BR_PWM, BR_DIR);

public:
  MotorController(bool headlessMode) {
    headless = headlessMode;
  };

private:
  //TL TR BL BR
  //getMotorSpeeds(float theta, float speed, float tilt) -> array<float, 4> motorSpeeds
  array<float, 4> getMotorSpeeds(float x, float y, float speed, float tilt, float offset) {
    //the effect that tilt has on the motors
    //convert to bearing
    tilt = 360 - tilt;
    if (tilt > 180) {
      tilt = -(360 - tilt);
    }

    if (tilt < TILT_RANGE and tilt > -TILT_RANGE) {
      tilt = 0;
    }
    
    // float t = 7.45*pow(abs(tilt), (1.0/2.0));
    // if (tilt < 0) {
    //   t = t*-1;
    // }

    // float o = 7.45*pow(abs(offset), (1.0/3.0));
    // if (offset < 0) {
    //   o = o*-1;
    // }

    Serial.print("Offset: ");
    Serial.println(offset);

    float motorRatio[4] = { -x - y, -x + y, x - y, x + y };
    // round motor Ratio to prevent errors
    for (int i = 0; i < 4; i++) {
      motorRatio[i] = round(motorRatio[i] * 1000) / 1000;
    }

    float highestVal = *max_element(motorRatio, motorRatio + 4);
    float lowestVal = *min_element(motorRatio, motorRatio + 4);

    float largest;
    if (highestVal > lowestVal * -1) {
      largest = highestVal;
    }
    else {
      largest = lowestVal * -1;
    }

    array<float, 4> motorSpeeds;

    //avoid division by 0
    if (largest == 0) {
      motorSpeeds = { tilt + offset, tilt + offset, tilt + offset, tilt + offset };
      return motorSpeeds;
    }

    for (int i = 0; i < 4; i++) {
      // +0.0 converts motorRatio to double
      motorSpeeds[i] = ((motorRatio[i] + 0.0) / largest * speed) + tilt + offset;
    }

    //TL, TR, BL, BR
    return motorSpeeds;
  };

public:
  array<float, 4> getMotorSpeeds() {
    return motorSpeeds;
  };
  float getSpeed() {
    return speed;
  };

  void setHeadless(bool headlessMode) {
    headless = headlessMode;
  };

  // sets speed in percentage
  void setSpeed(float newSpeed) {
    speed = newSpeed;
  };

  // acceleration and deacceleration functions (just change the speed)
  void accelerate(float step, float target) {
    speed += step;
    if (speed > target) {
      speed = target;
    }
  };
  void deaccelerate(float step, float target) {
    speed -= step;
    if (speed < target) {
      speed = target;
    }
  };

  // run motors using x and y coordinates (and tilt for gyro correction)
  void runMotors(float initial_x = 0, float initial_y = 0, float tilt = 0, float offset = 0) {
    float x = 0, y = 0;
    if (headless) {
      x = initial_x*cos(-tilt) - initial_y*sin(-tilt);
      y = initial_x*sin(-tilt) + initial_y*cos(-tilt);
    }
    else {
      x = initial_x, y = initial_y;
    }
      
    motorSpeeds = getMotorSpeeds(x, y, speed, tilt, offset);

    for (int i = 0; i < 4; i++) {
      if (motorSpeeds[i] > 100) {
        motorSpeeds[i] = 100;
      }
      else if (motorSpeeds[i] < -100) {
        motorSpeeds[i] = -100;
      }
    }

    // run motors
    TL.run(motorSpeeds[0]);
    TR.run(motorSpeeds[1]);
    BL.run(motorSpeeds[2]);
    BR.run(motorSpeeds[3]);
  };

  // run using raw motor speeds in percentage
  void runRaw(float tlSpeed, float trSpeed, float blSpeed, float brSpeed) {
    TL.run(tlSpeed);
    TR.run(trSpeed);
    BL.run(blSpeed);
    BR.run(brSpeed);
  };

  // stop all motors
  void stopMotors() {
    motorSpeeds = { 0, 0, 0, 0 };
    TL.stop();
    TR.stop();
    BL.stop();
    BR.stop();
  };
};

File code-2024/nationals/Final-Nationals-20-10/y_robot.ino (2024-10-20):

// main robot class
class Robot {
public:
  // defining objects
  MotorController mc = MotorController(false);
  Adafruit_BNO055 bno = Adafruit_BNO055(55);
  IRSensor ir;

  PositionSystem ps;

  // defining variables
  float tilt = 0;
  float offset = 0;
  int direction = 0, strength = 0;

  float x = 0, y = 0;

  int lineValue;
  float previousY;

private:
  /* :::::::: FUNCTIONS :::::::: */
  void getSensorData() {
    // READ IR
    ir.readData();
    direction = ir.getFilteredDirection();
    strength = ir.getFilteredStrength();

    // READ IMU
    sensors_event_t event;
    bno.getEvent(&event);
    tilt = event.orientation.x;

    // convert to unit circle tilt
    tilt = 360 - tilt;

    // get values from line sensor
    if (Serial6.available()) {
      lineValue = Serial6.read() - 1;
    }
  };
  
  void getBallXY(float& ballX, float& ballY) {
    ballX = cos(irAngles[direction]);
    ballY = sin(irAngles[direction]);
  };

public:
  void update() {
    // get sensor data using sensor classes
    getSensorData();
    Serial.println("Read sensors"); // code crashes without line between for some reason
    ps.update(tilt*PI/180);
  };

  // function for robot to position itself behind the ball
  void getBehindBall() {
    if (direction == 0) {
      x = 0, y = 0;
      return;
    }

    if (strength < 34) {
      getBallXY(x, y);
      return;
    }

    if (direction == 12) {
      x = 0, y = 1;
      return;
    }

    if (direction == 6) {
      x = 1, y = 0;
      return;
    }

    float movementAngle;

    float ballX = 0, ballY = 0;
    getBallXY(ballX, ballY);

    if (ballX < 0) {
      movementAngle = irAngles[direction] + PI/2;
    }
    else {
      movementAngle = irAngles[direction] - PI/2;
    }

    x = cos(movementAngle);
    y = sin(movementAngle);
  };

  // adjusting speed according to situation
  void adjustSpeed() {
    if (lineValue != 0) {
      mc.setSpeed(LINE_SPEED);
      return;
    }

    if (irAngles[direction] > PI && irAngles[direction] < 2*PI) {
      if (strength > 30) {
        mc.setSpeed(BALL_BEHIND_CLOSE_SPEED);
      }
      else {
        mc.setSpeed(BALL_BEHIND_SPEED);
      }
    }
    else {
      mc.setSpeed(100);
    }
  };

  // tilt towards goal
  void getOffset() {
    if (lineValue != 0 || !ps.reliable) {
      offset = 0;
      return;
    }

    if (ps.x < FIELD_WIDTH/2 - 20) {
      offset = 25;
    }
    else if (ps.x > FIELD_WIDTH/2 + 20) {
      offset = -25;
    }
    else {
      offset = 0;
    }

    // if (ps.x < 50) {
    //   offset = -30;
    // }
    // else if (FIELD_WIDTH - ps.x < 50) {
    //   offset = 0; // 30
    // }
    // else if (ps.x < (FIELD_WIDTH/2 - 20)) {
    //   offset = -20;
    // }
    // else if (ps.x > (FIELD_WIDTH/2 + 20)) {
    //   offset = 0; // 20
    // }
    // else {
    //   offset = 0;
    // }
  };

  // gets the goal x,y coordinants using ultrasonics
  void getGoalXY(float &x, float &y) {
    x = -(ps.x - GOAL_POS_X);
    y = ps.y - GOAL_POS_Y;
  };

  void targetGoal() {
    x = 0, y = 1;
    // if (!ps.reliable || direction != 12) {
    //   return;
    // }
    // getGoalXY(x, y);
  };

  // keep a record of previous Y heading
  void logY() {
    if (lineValue == 0) {
      previousY = y;
    }
  };

  // stays within the lines (lineValue 1 is front, 2 is left, 3 is right, 4 is back)
  void stopAtLine() {

    if (lineValue == 1 || lineValue == 4) {
      if(previousY < 0) x = 0, y = 1;
      else x = 0, y = -1;
    }

    else if (lineValue == 2) { // && (x < 0)
      if (ps.x < 40) {
        x = 1, y = 0;
      }
      else {
        // set speed to 100 as last resort to get out quick
        mc.setSpeed(100);
        x = -1, y = 0;
      }
    }
    else if (lineValue == 3) { //&& (x > 0)
      if (ps.x < 40) {
        // set speed to 100 as last resort to get out quick
        x = 1, y = 0;
      }
      else {
        mc.setSpeed(100);
        x = -1, y = 0;
      }
    }
  };

  void run() {
    // run motors using motor controller
    mc.runMotors(x, y, tilt, offset);
  };
};

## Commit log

2024-05-21 Ryan has entered 😎
2024-05-21 added pcb folder
2024-05-21 added gyro test program
2024-05-26 Added testing codes
    Codes for testing:
    Laser
    ultrasonic
    motors
    gyro
2024-06-07 Added new test codes for LCD, IR and all motors
2024-06-15 <-- THIS IS UPDATED CODE
    - updated for loops
    - changed 'idle' to match test motor
2024-06-17 added 3mf files
    [backup_pillar.3mf]
2024-06-19 added round to motor ratio
2024-06-19 Create motor_controller.cpp
    this code is for pure c++
    follow the instructions at the top to run in arduinoIDE
2024-08-19 Added teensy 4.1 - rasberry pi pico communication
    one file to be run on teensy (TeensyRP_Teensy.ino) and one to be run on the rasberrry pi pico (TeensyRP_RP.ino)
2024-09-14 Added dribbler testing and nationals_V1
    just uncomment the sections one by one in nationals_V1 to test. please do not burn teensys and do not let Cruz touch the code
    [Dribbler_Testing.ino, Nationals_v1.ino, functions.ino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]
2024-09-15 Updated version and corrected errors
    [Nationals_v1.ino, functions.ino, motor_controller.ino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]
2024-09-19 Colour sensor testing code (directly with RP)
    Does not communicate with teensy prints readings directly from RP
2024-09-27 added pcbs.txt
2024-09-28 added pcbs
    [line_sensor.kicad_pcb, line_sensor.kicad_sch, main_pcb_bottom.kicad_pcb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]
2024-09-28 added ir.cpp
    filters direction within class
2024-09-28 created prototype_ls_code.ino
2024-10-02 added design notes to metro
    [backup_pillar.3mf]
2024-10-05 fixed ps.y issue
    y = FIELD_WIDTH - trueBack;
    FIELD_LENGTH not FIELD_WIDTH
    [ultrasonic.ino]
2024-10-15 fixed undefined team data
    [y_robot.ino]
2024-10-17 fixed go forward at start
    [z_main.ino]
2024-10-17 fixed getSpeed function missing
    [motor_controller.ino]
2024-10-17 Fixed moving around ball hesitation
    [y_robot.ino]
2024-10-18 update ultrasonics
2024-10-19 fixed front and back stay within lines
    [y_robot.ino]
